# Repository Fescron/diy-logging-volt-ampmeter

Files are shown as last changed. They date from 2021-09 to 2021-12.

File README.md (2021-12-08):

# DIY Logging Volt/Ampmeter








<br/>

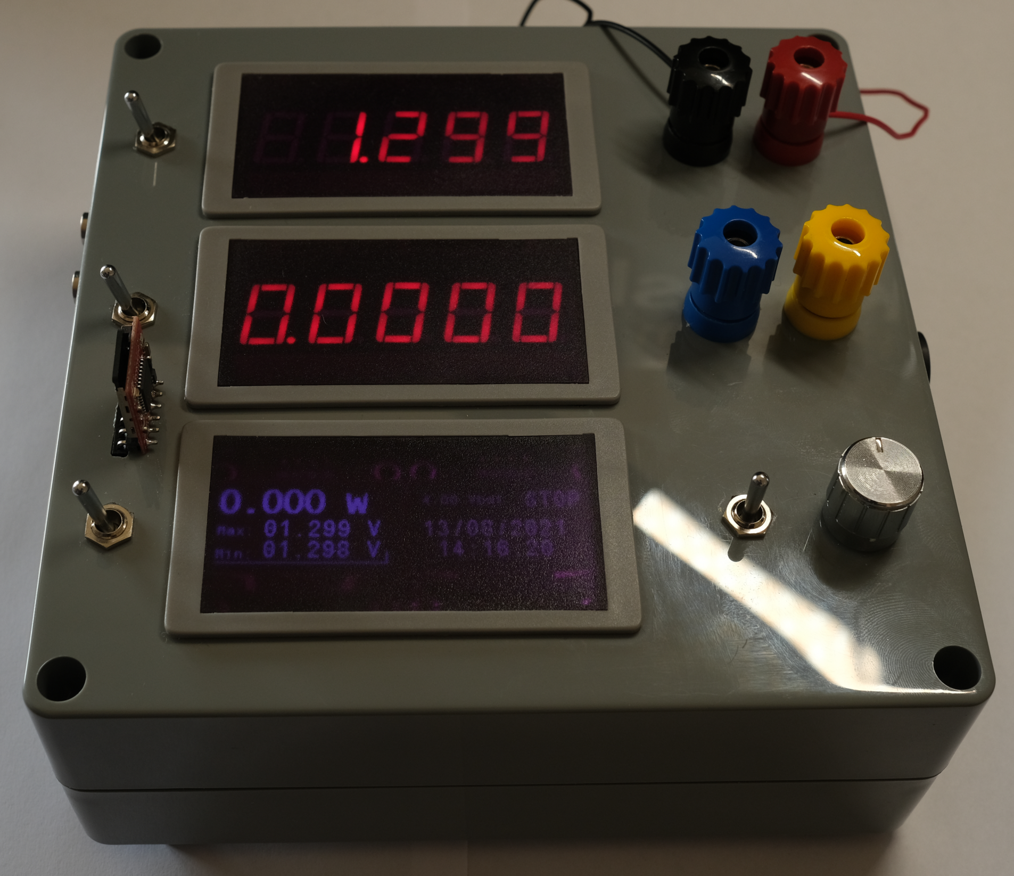
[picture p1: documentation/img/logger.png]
DIY Logging Volt/Ampmeter


<br/>

| Quick access links | |
|---|-----|
| [Carrier board v1.0 schematic (PDF)](hardware/high-accuracy-logging-volt-ampmeter/high-accuracy-logging-volt-ampmeter.pdf) | [Doxygen code documentation of individual files and methods](https://fescron.github.io/diy-logging-volt-ampmeter/files.html) |
| [Wiring diagram v1.0 (PDF)](hardware/wiring-diagram_diy-logging-volt-ampmeter/wiring-diagram_diy-logging-volt-ampmeter.pdf) | [Doxygen TODO's](https://fescron.github.io/diy-logging-volt-ampmeter/todo.html) |

<br/>

This battery-powered logging volt/ampmeter was made with the intention to easily get `.CSV` files filled with voltage/current/power measurements on a SD-card to plot and use this data further. It is supposed to have the same functionality as much more expensive dataloggers, with the added benefit of the ability to change the firmware to add more functions.

<br/>

## 0 - Table of Contents

- [DIY Logging Volt/Ampmeter](#diy-logging-voltampmeter)
  - [0 - Table of Contents](#0---table-of-contents)
  - [1 - Construction](#1---construction)
  - [2 - Usage](#2---usage)
  - [3 - Bash script to generate plots (logplot)](#3---bash-script-to-generate-plots-logplot)
  - [4 - Additional hardware changes (carrier board v1.0)](#4---additional-hardware-changes-carrier-board-v10)
  - [5 - Future code-additions](#5---future-code-additions)

<br/>

## 1 - Construction

DIY Logging Volt/Ampmeter

<br/>

The device consists of **two Chinese** (but very accurate and highly functional) **meters** ([BY56W 50V](https://aliexpress.com/item/32840631947.html) and [BY56W 5A](https://aliexpress.com/item/32839044728.html)) with independent power-supplies so no *common-mode* errors can occur. They can be individually powered on or off with **toggle switches** left of these meters. On the right of them are **combination banana- and screw-terminals** to easily connect measurement cables. The black and red one are the negative and positive terminal of the voltmeter, the blue and yellow one are the negative and positive terminal of the current meter. In series with the latter plugs and the current meter are a **5A 5x10mm fuse** (fitted in a holder on right right side of the logger), along with an **5V internal NC-relay** (with a [5V boostconverter](https://aliexpress.com/item/32891706812.html) and protection-diode) to open the current connection in certain scenarios (over-voltage, over-current, under-voltage, ...). Currently no code is written to use this relay functionality.

On the bottom a **third module** with the same shell as the voltage and current meters (I asked the Chinese store if they could sell me some) is situated with **two [1.3" 128x64 I2C OLED-displays](https://aliexpress.com/item/32830144222.html)** and a **STM32 Blue-Pill board** (with a genuine (!) ST `STM32F103C8T6` microcontroller). This functions as the brains of the whole unit. This bottom module can also be switched on or off with the **toggle switch** to the left. The display-module *asks* the two meters for measurement values and does additional conversions and calculations with them, drives the displays, keeps the time with its **internal RTC and 3V coincell backup-battery**, reads the battery voltage, outputs the measurements to the UART port on top, ... Next to the bottom module an **up/down monostable toggle switch** and **[pressable rotary encoder](https://aliexpress.com/item/32915420023.html)** can be used to start or stop logging, view measurements, change settings, ...

This module however **does not write the data to a SD-card directly**. For this a **[Sparkfun OpenLog](https://www.sparkfun.com/products/13712) module** has to be plugged in to the **external UART port on top**. Because of the way the firmware is developed, a new `.TXT` file is created each time a new measurement-session is started. The resulting file can be easily renamed to a `.CSV` file to facilitate importing in *Excel* or *OpenOffice Calc*. The first line of the file contains a header which explains what data goes where in the following measurement-lines. The last two lines of the file contain another header with corresponding data like date, total runtime, capacity and maximum/minimum values.

The whole thing is powered by **two (parallel) 18650 batteries** in a [battery holder](https://aliexpress.com/item/32832636191.html). A [charge and battery-protection PCB](https://aliexpress.com/item/32666559864.html) facilitates charging at 1A using **USB Type-C** on the left side of the meter. I used a [breakout-board](https://aliexpress.com/item/4001299632280.html) with two 5.1k resistors on the `CC1` and `CC2` pins to activate the 5V output on USB-PD compliant chargers. Above this Type-C port ***charging* and *done* LED's** are also fitted. Right of this the **programming-port** and two **external GPIO-pins** with a 3.3V and GND terminal on *Dupont*-connectors are situated. These two external GPIO-pins however currently have no function. Internally there also is a **buzzer** which can be used to signal various states, but no code is written to use this functionality as well. Some buck-boost converters (after the toggle switches) are also placed on a prototype-PCB to convert the battery voltage to 5V (with [these boostconverters](https://aliexpress.com/item/32891706812.html)) for the meters and 3.3V (with [this buck/boostconverter](https://aliexpress.com/item/32822323191.html)) for the bottom STM32-display-module.

The picture below depicts the internal wiring-diagram, standalone modules/boards are surrounded in blue frames.

<br/>

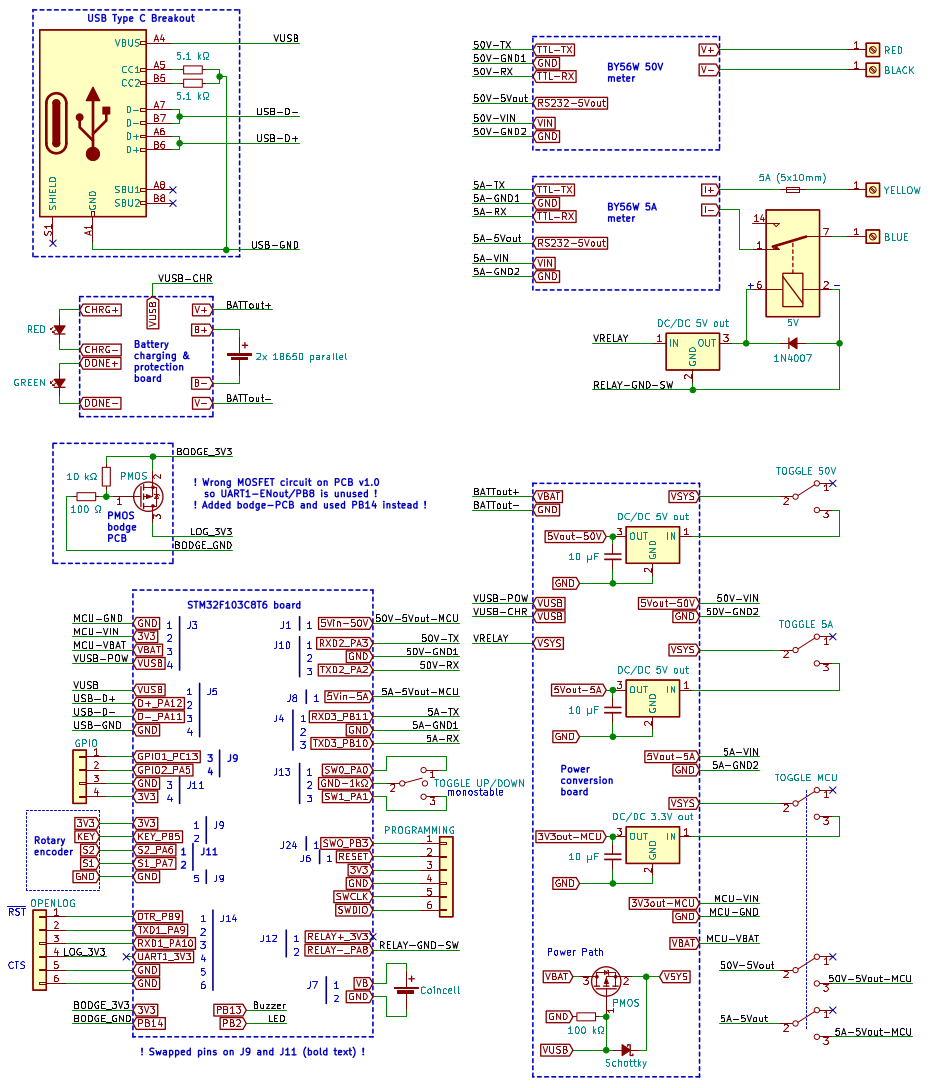
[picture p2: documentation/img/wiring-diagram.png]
Wiring diagram


<br/>

## 2 - Usage

The **up/down monostable toggle-switch** and **pressable rotary encoder** on the right of the bottom display-module are used to switch between display-pages and to set various settings.

The **left display** always indicates the power on the top. If the display is selected (*selection-line* drawn on the bottom of the display) the rotary encoder can be used to switch between the different pages to display additional information: max/min voltage, max/min current and calculated capacity in Ah and Wh. Upon an encoder-press the displayed information can be reset (if the logger is not saving data to a SD-card). Below these three available pages on the left display are depicted.

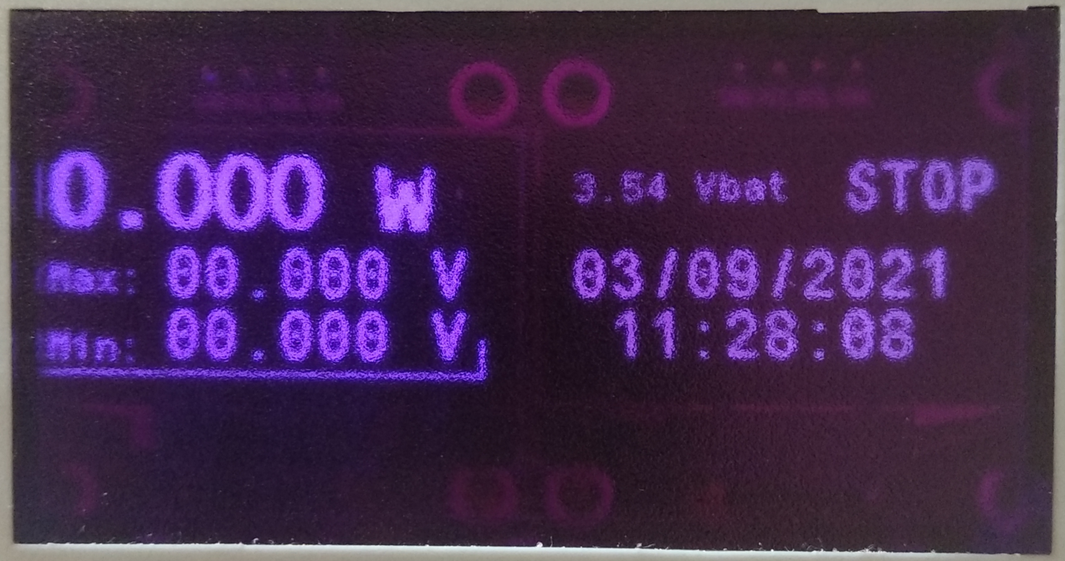
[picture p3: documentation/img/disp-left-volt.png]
Left display selected, max/min volt
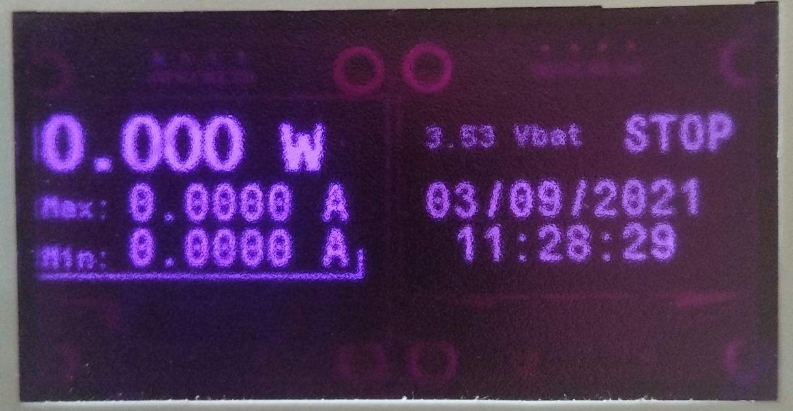
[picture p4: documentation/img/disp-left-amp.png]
Left display selected, max/min amp
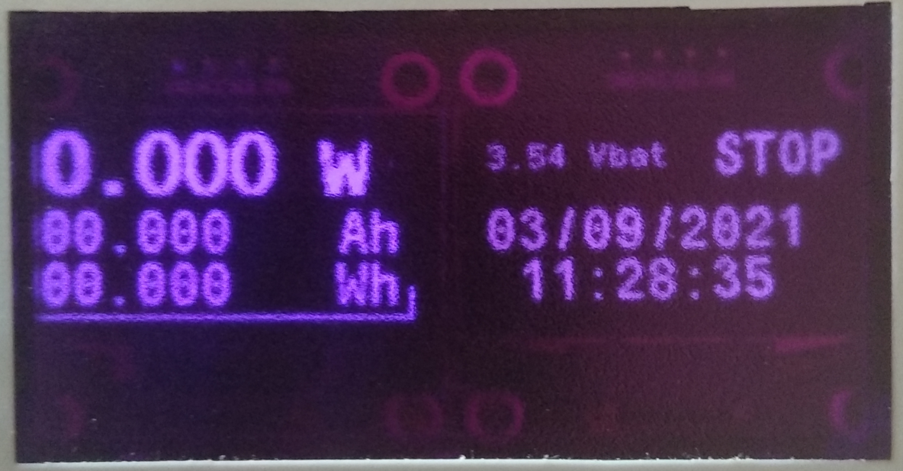
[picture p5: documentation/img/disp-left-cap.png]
Left display selected, capacity


<br/>

A down-press on the monostable toggle-switch changes the selected display. The *selection-line* on the bottom of the display will be moved to the newly selected display.

The **right display** always indicates the internal battery voltage and state of the logger (`STOP/START/RUN/SAVE`) on the top. If this display is selected (*selection-line* drawn on the bottom of the display) the rotary encoder can again be used to switch between the different pages to display additional information. The first page displays the current date and time, and pressing the encoder enables the user to change this information. Values are changed by rotating the encoder, the value (for example the day) is saved on an encoder-press, and the next item (for example the month) can now be edited. The second page displays the period between measurements saved to the logfile with the external logger. Pressing the encoder activates the ability to change the period by rotating the encoder, pressing it again saves the value. The third page displays the runtime if the logger is saving data to the external logger. Below these three available pages on the right display are depicted.

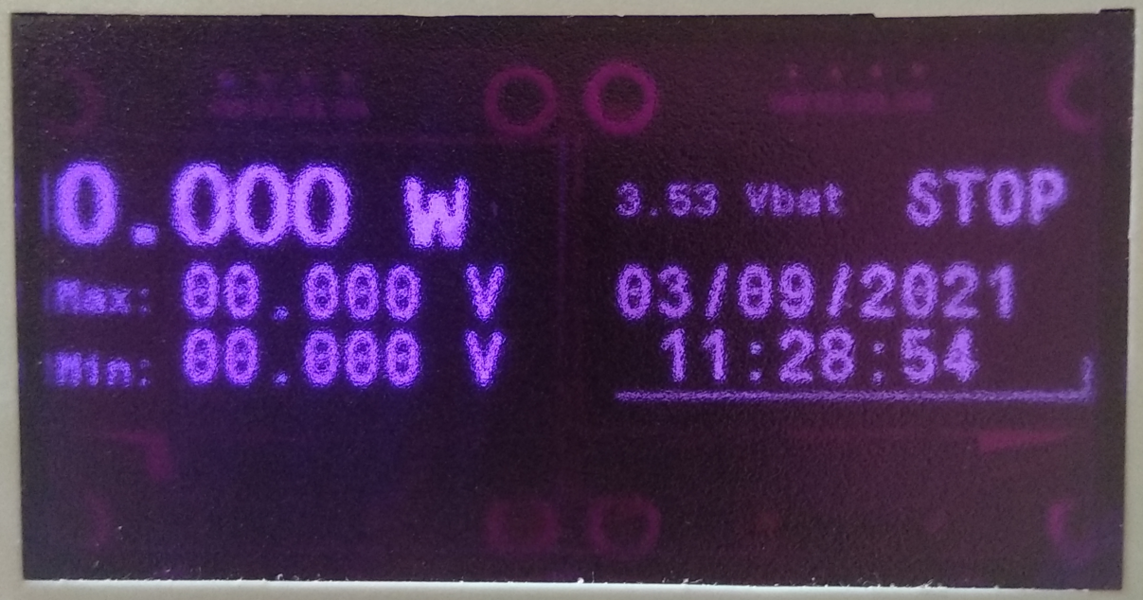
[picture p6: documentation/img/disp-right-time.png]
Right display selected, date/time
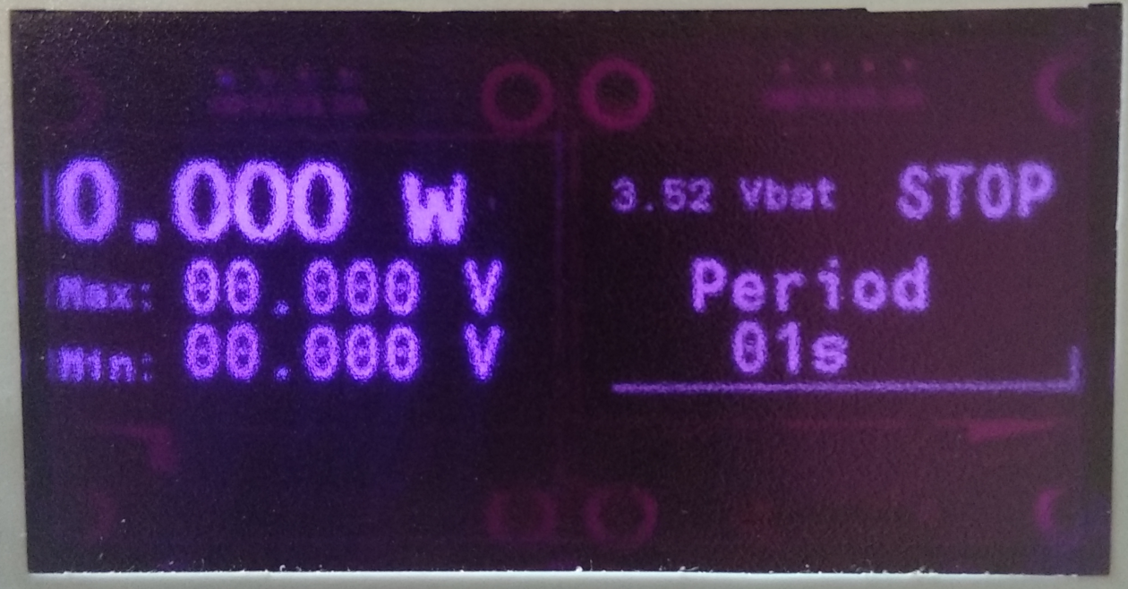
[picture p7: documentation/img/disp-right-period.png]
Right display selected, measurement period
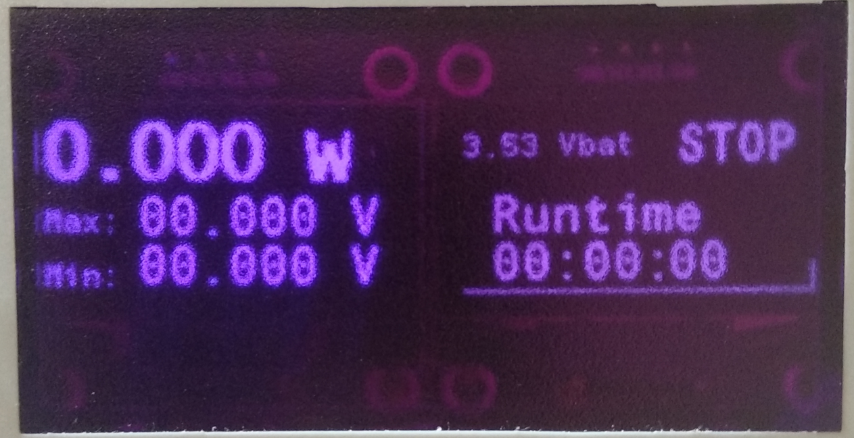
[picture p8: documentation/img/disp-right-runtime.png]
Right display selected, runtime


<br/>

An up-press on the monostable toggle switch (if the logger is in `STOP`-mode) powers-up the external logger (`START`) and writes the *header*, along with a first measurement-line to the `.TXT` file (`SAVE`). Then the logger waits (`RUN`) until the measurement-period runs out and writes another measurement to the file (`SAVE`). Another up-press on the monostable toggle switch stops the logging and writes two more lines to the end of the file including data as the date, total runtime, capacity, max/min values, ... An example of the resulting data in such a `.TXT` file is depicted below.

```
Time [hour:min:sec],Runtime [hour:min:sec],Voltage [V],Current [A],Power [W]
17:46:21,00:00:01,1.291,0.0000,0.000
17:46:23,00:00:03,1.291,0.0000,0.000
17:46:25,00:00:05,1.291,0.0000,0.000
17:46:27,00:00:07,1.291,0.0000,0.000
17:46:29,00:00:09,0.875,0.0000,0.000
17:46:31,00:00:11,1.092,0.0000,0.000
17:46:33,00:00:13,1.290,0.0000,0.000
Date [day/month/year],Runtime [hour:min:sec],Capacity [Ah],Capacity [Wh],Max Volt [V],Min Volt [V],Max Curr [A],Min Curr [A]
17/08/2021,00:00:13,00.000,00.000,01.291,00.000,0.0000,0.0000
```

<br/>

## 3 - Bash script to generate plots (logplot)

To easily convert the `.txt`/`.csv` files from this meter and get **plots in PDF-form**, a bash-script using `gnuplot` and `ps2pdf`/`imagemagick` was created. To create a PDF-plot of a file (`LOG00110.TXT`) with the title "Title" and subtitle "Subtitle", and to make sure the capacity and max/min voltage and current values are displayed above the graph, one can use the following command:

```bash
logplot -f "LOG00110.TXT" -t "Title" -st "Subtitle" -av
```

<br/>

Below is a list of all of the possible commands, which can also be shown with the command `logplot -h`. The bash-script itself can be found [here](software/logplot)

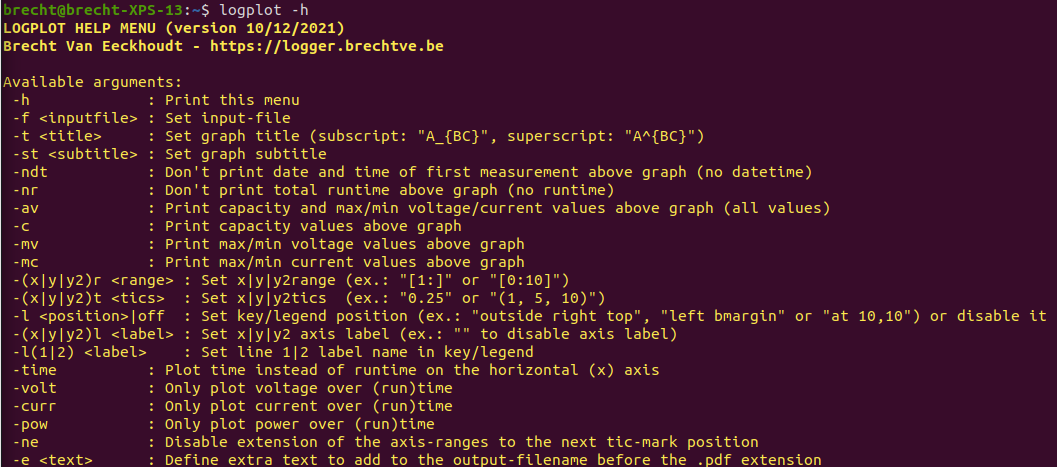
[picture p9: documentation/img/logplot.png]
Logplot help menu


<br/>

## 4 - Additional hardware changes (carrier board v1.0)

To simplify the firmware for the rotary encoder logic some pins were swapped around on header `J9` and `J11`. This is highlighted by bold text on the wiring-diagram on the **STM32F103C8T6 board**.

Unfortunately a wrong MOSFET was used for the function to power the external Openlog UART datalogger on or off. This means that MCU pin `UART1-ENout/PB8` is unused and a **PMOS bodge PCB** was constructed. This can be seen on the wiring-diagram. MCU pin `PB14` is used instead to power the logger.

<br/>

## 5 - Future code-additions

The firmware is constructed with a lot of extra variables to facilitate the functionality to only update changed values on the displays. This speeds up the code but does however create a lot of *overhead*. In the future this can certainly be optimized.

As of yet not all of the hardware is used, like for example the relay and buzzer. All TODO's can be found in the [Doxygen TODO's](https://fescron.github.io/diy-logging-volt-ampmeter/todo.html).

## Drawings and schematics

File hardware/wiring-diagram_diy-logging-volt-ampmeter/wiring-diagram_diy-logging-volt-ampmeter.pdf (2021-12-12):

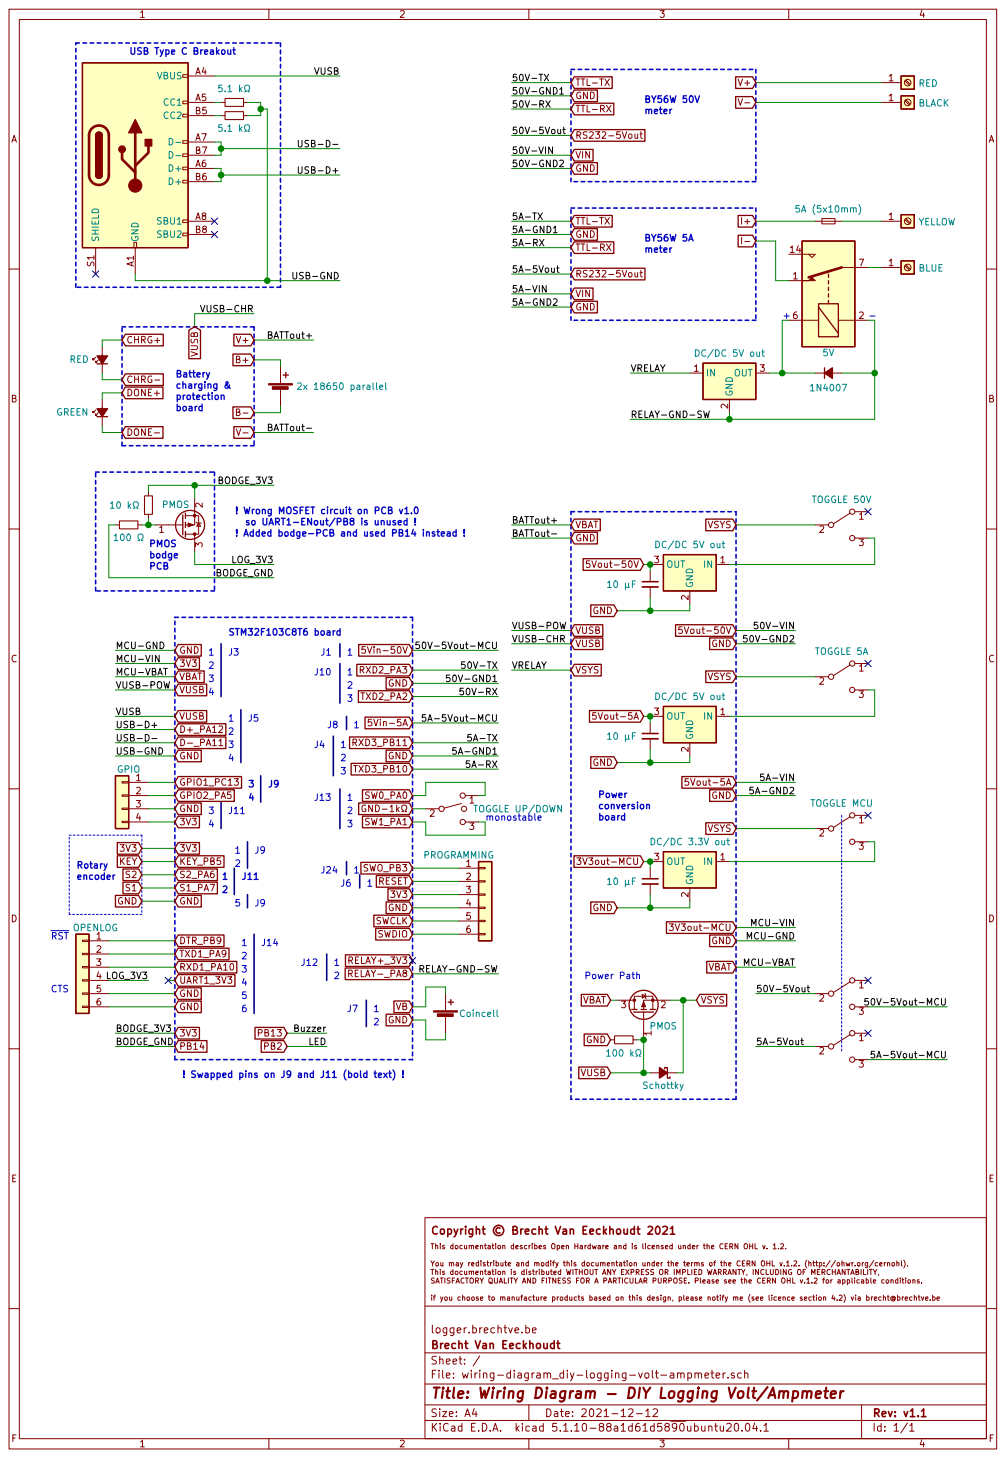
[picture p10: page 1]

2 OUT 3 DC/DC 5V out 1

! Wrong MOSFET circuit on PCB v1.0
so UART1-ENout/PB8 is unused !
! Added bodge-PCB and used PB14 instead ! 3

! Swapped pins on J9 and J11 (bold text) !

Copyright © Brecht Van Eeckhoudt 2021

This documentation describes Open Hardware and is licensed under the CERN OHL v. 1.2.

You may redistribute and modify this documentation under the terms of the CERN OHL v.1.2. (http://ohwr.org/cernohl).

logger.brechtve.be
File: wiring-diagram_diy-logging-volt-ampmeter.sch Sheet: / Brecht Van Eeckhoudt

Id: 1/1 Title: Wiring Diagram - DIY Logging Volt/Ampmeter

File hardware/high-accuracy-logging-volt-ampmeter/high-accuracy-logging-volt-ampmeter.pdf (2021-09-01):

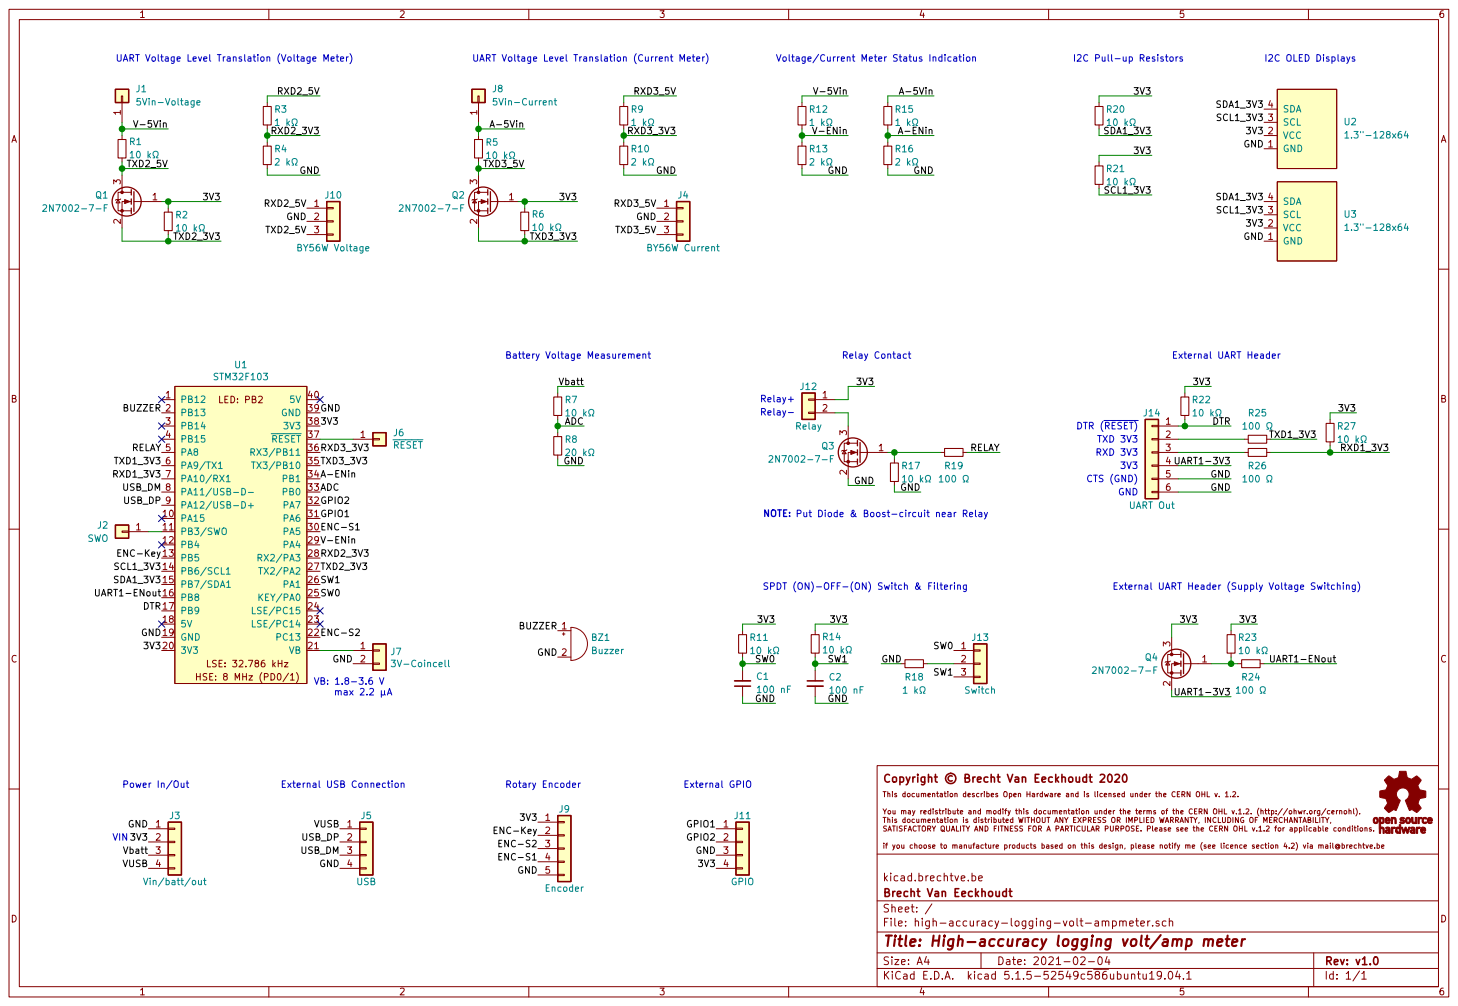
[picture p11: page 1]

RXD 3V3 SPDT (ON)-OFF-(ON) Switch & Filtering

NOTE: Put Diode & Boost-circuit near Relay VB: 1.8-3.6 V

External UART Header (Supply Voltage Switching)

File: high-accuracy-logging-volt-ampmeter.sch Sheet: / Brecht Van Eeckhoudt kicad.brechtve.be Copyright © Brecht Van Eeckhoudt 2020

This documentation describes Open Hardware and is licensed under the CERN OHL v. 1.2.

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

Id: 1/1 Title: High-accuracy logging volt/amp meter

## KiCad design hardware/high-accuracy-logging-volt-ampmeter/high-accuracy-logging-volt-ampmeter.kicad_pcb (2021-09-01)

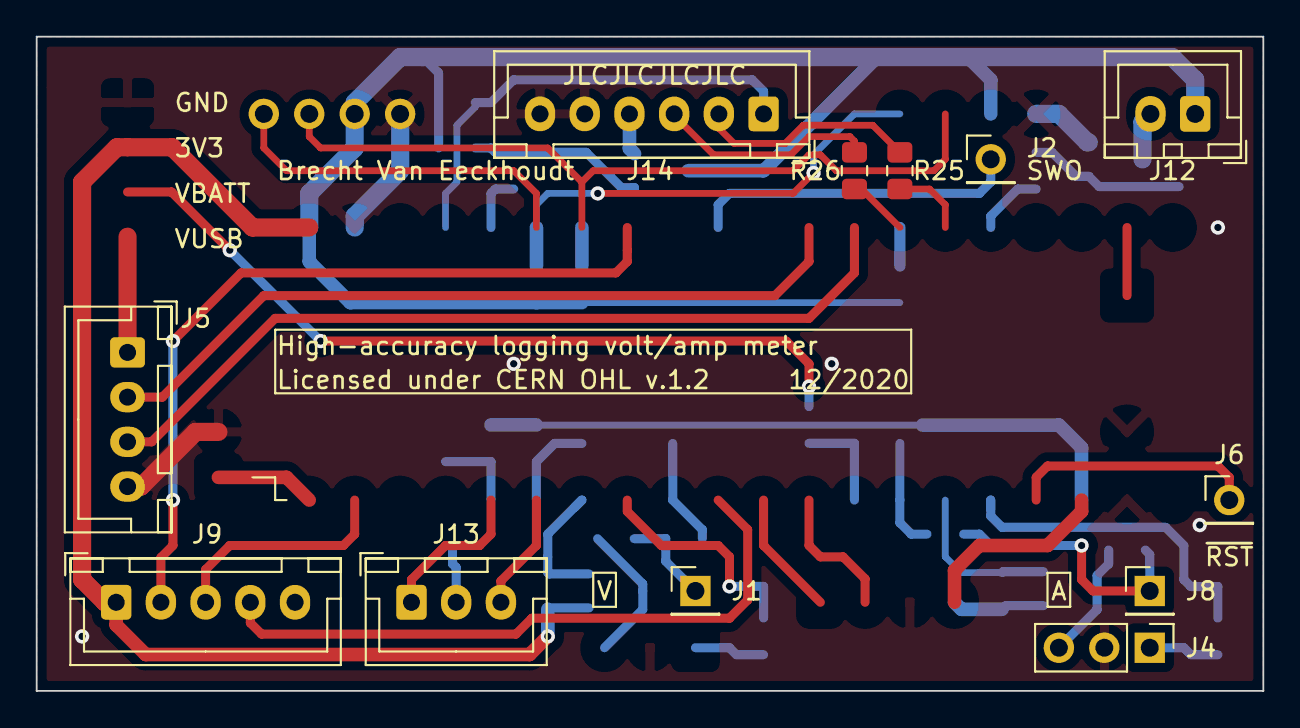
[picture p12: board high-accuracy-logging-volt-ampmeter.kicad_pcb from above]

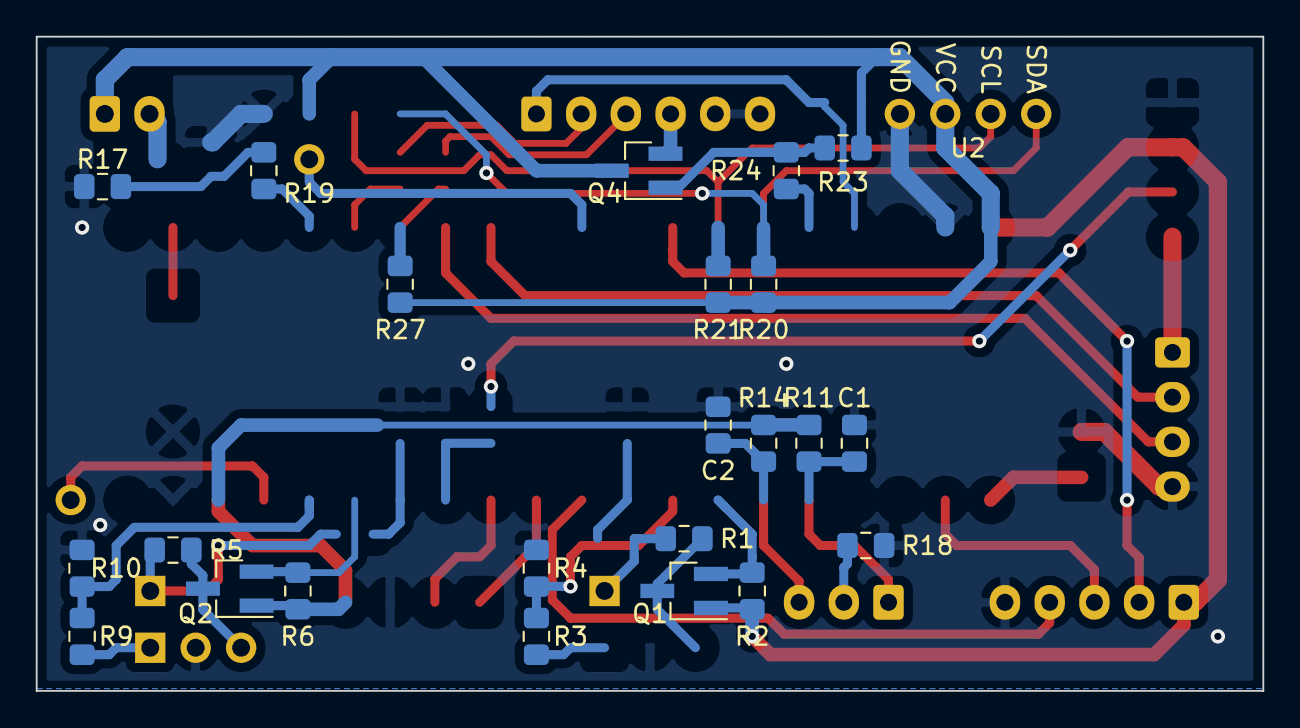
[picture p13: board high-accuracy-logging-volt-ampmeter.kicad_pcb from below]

Board: 2 copper layers, 68.6 x 36.6 mm, 37 parts (24 on the bottom side), 22 nets.

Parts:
C1, C2: 100 nF; C_0805_2012Metric_Pad1.15x1.40mm_HandSolder
G1: Symbol_OSHW-Logo_11.4x12mm; OSHW-Logo_5.7x6mm_SolderMask
J1: 5Vin-Voltage; PinHeader_1x01_P2.54mm_Vertical
J2: SWO; PinHeader_1x01_P2.54mm_Vertical
J4: BY56W Voltage; PinHeader_1x03_P2.54mm_Vertical
J5: USB; JST_XH_B4B-XH-A_1x04_P2.50mm_Vertical
J6: ~RESET; PinHeader_1x01_P2.54mm_Vertical
J8: 5Vin-Current; PinHeader_1x01_P2.54mm_Vertical
J9: Encoder; JST_XH_B5B-XH-A_1x05_P2.50mm_Vertical
J12: Relay; JST_XH_B2B-XH-A_1x02_P2.50mm_Vertical
J13: Switch; JST_XH_B3B-XH-A_1x03_P2.50mm_Vertical
J14: UART Out; JST_XH_B6B-XH-A_1x06_P2.50mm_Vertical
Q1, Q2, Q4: 2N7002-7-F; SOT-23_Handsoldering
R1, R2, R5, R6, R11, R14, R17, R20, R21, R23, R27: 10 kΩ; R_0805_2012Metric_Pad1.15x1.40mm_HandSolder
R3, R9, R18: 1 kΩ; R_0805_2012Metric_Pad1.15x1.40mm_HandSolder
R4, R10: 2 kΩ; R_0805_2012Metric_Pad1.15x1.40mm_HandSolder
R19, R24, R25, R26: 100 Ω; R_0805_2012Metric_Pad1.15x1.40mm_HandSolder
U2: 1.3; 1.3INCH-128x64-I2C-OLED-NoHoles

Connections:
/3V3: J9.1, J12.1, Q1.1, Q2.1, Q4.3, R2.1, R6.2, R11.1, R14.2, R20.1, R21.1, R23.1, R27.1, U2.2
/A-5Vin: J8.1, R5.1
/GND: C1.1, C2.2, J4.2, J5.4, J9.5, J14.5, J14.6, R4.2, R10.2, R17.2, R18.2, U2.1
/RXD1_3V3: R26.2, R27.2
/RXD2_3V3: R3.2, R4.1
/RXD3_3V3: R9.2, R10.1
/RXD3_5V: J4.1, R9.1
/SCL1_3V3: R21.2, U2.3
/SDA1_3V3: R20.2, U2.4
/SW0: C1.2, J13.1, R11.2
/SW1: C2.1, J13.3, R14.1
/TXD2_3V3: Q1.2, R2.2
/TXD2_5V: Q1.3, R1.1
/TXD3_3V3: Q2.2, R6.1
/TXD3_5V: J4.3, Q2.3, R5.2
/UART1-3V3: J14.4, Q4.2
/V-5Vin: J1.1, R1.2
unnamed: J13.2, R18.1
unnamed: J14.2, R25.2
unnamed: J14.3, R26.1
unnamed: R17.1, R19.2
unnamed: Q4.1, R23.2, R24.2

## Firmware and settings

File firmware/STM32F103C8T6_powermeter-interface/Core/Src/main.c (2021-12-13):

/* USER CODE BEGIN Header */

/***************************************************************************//**
 * @file main.c
 * @brief Main source-file for the high-precision logging voltage/current meter project.
 * @details
 *   The code in this project asks two BY56W volt/current meters for measurements,
 *   calculates a few additional values (min/max/power/Ah/Wh) with these, prints
 *   them to displays and sends them (with time/date values) to a UART port so
 *   a Sparkfun OpenLog can log these measurements to a `.TXT` file, which can
 *   eventually be renamed to a `.CSV` so the measurements can be easily plotted.
 * @version 1.2
 * @author Brecht Van Eeckhoudt
 *
 * ******************************************************************************
 *
 * @section Versions
 *
 *   @li v1.0: Initial version.
 *   @li v1.1: Started printing date before time for each measurement-line, removed day-writing in footer.
 *   @li v1.2: Compared power floats more reliably.
 *
 * ******************************************************************************
 *
 * @todo
 *   **Things to do in the near future:**@n
 *     - Check Ah/Wh calculations.
 *     - Check if the power/Ah/Wh calculations are done using wrong/old measurements.
 *     - Handle uint32_t wraparound for time between calculations measurements and waiting time.
 *     - Don't send/do certain functions if one of the meters is powered down.
 *
 * @todo
 *   **Long-term future improvements:**@n
 *     - Add function to stop measurements when the voltage/current is (above/) below a certain value.
 *     - Add external temperature reading functionality.
 *     - Add internal temperature reading functionality (`MX_ADC1_Init();`).
 *     - Add interrupt-logging functionality.
 *     - Add relay-opening functionality.
 *     - Add "manual measurement-mode" to log on up-button press.
 *     - Add "performance-mode" with no display refreshes.
 *        - (sub-page on right display, start/stop with up, beeps for confirmation)
 *     - Add low-battery beeping.
 *     - Add buzzer functionality using TIM2 (`MX_TIM2_Init();`).
 *        -  (short beep button-press, longer when measurement taken, add ON/OFF settings page)
 *     - Optimize encoder logic so there is less copy-pasting.
 *     - Add debounce logic to `getSW0();`, `getSW1();` and `getENCkey();`.
 *     - Use `LL_GetTick();` instead of `HAL_GetTick();`?
 *     - Add circular pages for setting day/month/hour/minute/second (`changeDateTime`).
 *     - Add day-checking in function of the month?
 *     - Use defines for circular pages?
 *     - Start using `aBY56W_ContinuousRead`? Send on every meter power-up?
 *     - Only one while-loop (`USART_HandleContinuousReception`) when one meter is
 *       connected, way more if both are? Optimize this?
 *     - Add overflow catch if data.voltage/current are negative values?
 *        - `data.power > 999.999`, `data.ah > 9999.999`, `data.wh > 9999.999`
 *     - Remove all Segger-RTT functionality?
 *     - Store settings in power-down-safe memory.
 *
 * ******************************************************************************
 *
 * @section License
 *
 *   **Copyright (C) 2021 - Brecht Van Eeckhoudt**
 *
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
 *   *A copy of the GNU General Public License can be found in the `LICENSE`
 *   file along with this source code.*
 *
 *   @n
 *
 *   Some methods also use code obtained from examples from STMicroelectronics.
 *
 *   **Copyright (c) 2020 STMicroelectronics. All rights reserved.**
 *
 *   These sections are licensed by ST under BSD 3-Clause license, the "License";
 *   One may not use these example files except in compliance with the License.
 *   One may obtain a copy of the License at: opensource.org/licenses/BSD-3-Clause
 *
 ******************************************************************************/

/* USER CODE END Header */
/* Includes ------------------------------------------------------------------*/
#include "main.h"
#include "adc.h"
#include "i2c.h"
#include "tim.h"
#include "gpio.h"

/* USER CODE BEGIN Includes */

#include "usart.h"      /* UART communication functionality */
#include "SEGGER_RTT.h" /* Segger RTT debugging functionality */
#include "util.h"       /* Utility functionality */
#include "conversion.h" /* Conversion and settings */
#include "display.h"    /* Display functionality */
#include "rtc.h"        /* Real Time Clock and Calendar functionality */

/* USER CODE END Includes */

/* USER CODE BEGIN PD */

/** Max amount of while loop passes before exiting the while loop early (~meter unresponsive) */
#define MAX_WHILELOOPS_METER_RESPONSE 9000

/** Waiting time before shutting down the external UART logger after writing the footer */
#define SHUTDOWN_DELAY_UART_MODULE_MS 500

/** Waiting time for an external UART power-up message before writing the header */
#define STARTUP_DELAY_UART_MODULE_MS  2000

/** Time between battery voltage measurements */
#define VBAT_MEASUREMENT_PERIOD_S     10

/* USER CODE END PD */


/* USER CODE BEGIN PV */

/* BY56W meter commands */
static const uint8_t aBY56W_SingleRead[4]     = {0x88, 0xAE, 0x00, 0x11}; /* 0x00 = Device address */
//static const uint8_t aBY56W_ContinuousRead[4] = {0x88, 0xAE, 0x00, 0x21}; /* 0x00 = Device address */
//static const uint8_t aBY56W_StopRead[4]       = {0x88, 0xAE, 0x00, 0x01}; /* 0x00 = Any byte */

/* Data in structs */
struct Data_t         data;     /* Measurement data (changes a lot) */
struct cData_t        cData;    /* Measuremtn data converted to char-arrays */
struct Settings_t     settings; /* General data/settings (changes less frequently */
struct RTC_dateTime_t rtc;      /* Date and time */

/** LUT for period selection [s] (0 = as fast as possible) */
static const uint16_t LUT_period_s[16] = {0, 1, 2, 5, 10, 15, 30, 60, 120, 300, 600, 900, 1800, 3600, 7200, 18000};

/** Length of LUT */
static const uint8_t LUT_period_s_length = 16;

/* USER CODE END PV */

void SystemClock_Config(void);
/* USER CODE BEGIN PFP */

void writeHeader(void);
void writeFooter(void);
void writeMeasurements(void);
void checkEncoder(void);
void checkSwitches(void);

/* USER CODE END PFP */

/**
  * @brief  The application entry point.
  * @retval int
  */
int main(void)
{
  /* MCU Configuration--------------------------------------------------------*/

  /* Reset of all peripherals, Initializes the Flash interface and the Systick. */
  HAL_Init();

  /* Configure the system clock */
  SystemClock_Config();

  /* Initialize all configured peripherals */
  MX_GPIO_Init();
//  MX_ADC1_Init();
  MX_I2C1_Init();
  MX_ADC2_Init();
  MX_TIM3_Init();
//  MX_TIM2_Init();
  /* USER CODE BEGIN 2 */

  /* Power down UART voltage output */
  LL_GPIO_SetOutputPin(UART1_3V3out_GPIO_Port, UART1_3V3out_Pin); /* P-MOS so inverted logic! */

  /* Power up UART DTR (~reset)-pin so we're not resetting the module */
  LL_GPIO_SetOutputPin(UART1_DTRout_GPIO_Port, UART1_DTRout_Pin);


  /* Enable output channel 1 (rotary encoder) */
  LL_TIM_CC_EnableChannel(TIM3, LL_TIM_CHANNEL_CH1 | LL_TIM_CHANNEL_CH2);

  /* Enable counter */
  LL_TIM_EnableCounter(TIM3);

  /* Force update generation */
  LL_TIM_GenerateEvent_UPDATE(TIM3);


  /* Initialize date/time functionality */
  RTC_Init();


  /* Enable the update interrupt (logging-timing) */
//  LL_TIM_EnableIT_UPDATE(TIM2); // TODO change to buzzer timing

  /* Enable counter */
//  LL_TIM_EnableCounter(TIM2); // TODO change to buzzer timing

  /* Force update generation */
//  LL_TIM_GenerateEvent_UPDATE(TIM2); // TODO change to buzzer timing


  /* Initialize UART functionality */
  USART1_INIT();
  USART2_INIT();
  USART3_INIT();

  /* Initialize structs */
  initDataStruct();
  initSettingsStruct();

  /* Activate ADC for battery voltage measurements */
  Activate_ADC();

  /* Clear Terminal for Segger RTT functionality */
  SEGGER_RTT_WriteString(0, RTT_CTRL_CLEAR"START\r\n");

  /* Initialize displays */
  initDisplays();

  /* Disable buzzer */
//  LL_GPIO_ResetOutputPin(Buzzer_GPIO_Port, Buzzer_Pin);

//	  LL_GPIO_TogglePin(Relay_GPIO_Port, Relay_Pin);
//	  LL_GPIO_TogglePin(Buzzer_GPIO_Port, Buzzer_Pin);


//  SEGGER_RTT_printf(0, "%sTime:%s%s %.7d\n\r",
//                        RTT_CTRL_RESET,
//                        RTT_CTRL_BG_BRIGHT_RED,
//                        RTT_CTRL_TEXT_BRIGHT_WHITE,
//                        1111111
//                        );
//  SEGGER_RTT_WriteString(0, RTT_CTRL_RESET"Red: "RTT_CTRL_TEXT_BRIGHT_RED"This text is red."RTT_CTRL_TEXT_BLACK""RTT_CTRL_BG_BRIGHT_RED"This background is red. "RTT_CTRL_RESET"Normal text again.\n\r");
//	SEGGER_RTT_printf(0, "Value = %x\r\n", value);
//	SEGGER_RTT_printf(0, RTT_CTRL_RESET"%-.3d ", value);
//	SEGGER_RTT_printf(0, RTT_CTRL_TEXT_BRIGHT_RED"0x%.2x ", value);


  /* USER CODE END 2 */

  /* Infinite loop */
  /* USER CODE BEGIN WHILE */
  while (1)
  {
    /* USER CODE END WHILE */

    /* USER CODE BEGIN 3 */

	  checkEncoder();
	  checkSwitches();

	  USART2_SendCommand(aBY56W_SingleRead, 4); /* Voltage */
	  USART3_SendCommand(aBY56W_SingleRead, 4); /* Current */

	  uint16_t whileLoops = 0;

	  while (!(data.voltReceived) && !(data.currReceived) && (whileLoops < MAX_WHILELOOPS_METER_RESPONSE))
	  {
		  USART_HandleContinuousReception();
		  whileLoops++;
	  }

//	  SEGGER_RTT_printf(0, "%d ", whileLoops);

	  if (whileLoops < MAX_WHILELOOPS_METER_RESPONSE)
	  {
		  /* Store tick-value of latest measurements */
		  if (data.latestMScounter == 0)
		  {
			  data.msCounter1 = HAL_GetTick();
			  data.latestMScounter = 1;
		  }
		  else if (data.latestMScounter == 1)
		  {
			  data.msCounter0 = HAL_GetTick();
			  data.latestMScounter = 0;
		  }
	  }

	  /* Calculate power, Ah and Wh */
	  if (data.voltReceived || data.currReceived)
	  {
		  data.power = data.voltage * data.current;
		  if (data.power > 999.999) data.power = 999.999;

		  /* Convert floats to uint32_t (power has 3 decimal places: *1000) */
		  uint32_t oldPower = FLOAT_TO_INT(data.oldPower*1000);
		  uint32_t power = FLOAT_TO_INT(data.power*1000);

		  if (oldPower != power)
		  {
			  data.oldPower = data.power;
			  data.newPow = 1;
		  }

		  /* Calculate time between measurements */
		  uint32_t msTime = 0;
		  if (data.latestMScounter == 0) msTime = data.msCounter0 - data.msCounter1;
		  else if (data.latestMScounter == 1) msTime = data.msCounter1 - data.msCounter0;

//			  SEGGER_RTT_printf(0, "%dms ", msTime);

		  data.ah += data.current * ((float)msTime / 3600000.0);
		  if (data.ah > 9999.999) data.ah = 9999.999;

		  data.newAh = 1;

		  data.wh += data.power * ((float)msTime / 3600000.0);
		  if (data.wh > 9999.999) data.wh = 9999.999;

		  data.newWh = 1;
	  }

	  data.voltReceived = 0;
	  data.currReceived = 0;

	  /* Change variables if one second is elapsed */
	  if (decSecondPassed())
	  {
		  /* Signal (second) conversion logic */
		  settings.newSec = 1;

		  /* Get new RTC values if not changing the date/time manually */
		  if ((settings.changeDateTime == 0) && (settings.secPassed == 0)) readFromRTC();

		  /* Update runtime if running */
		  if ((settings.mode == 1) && settings.loggerReady)
		  {
			  if (settings.remMeasPeriodS > 0) settings.remMeasPeriodS--;

			  /* Re-calculate runtime */
			  if (data.runSecs < 59) data.runSecs++;
			  else if (data.runSecs == 59)
			  {
				  if (data.runMins < 59) data.runMins++;
				  else if (data.runMins == 59)
				  {
					  if (data.runHours < 99) data.runHours++;

					  data.newRunHours = 1; /* Display needs updating */
					  data.runMins = 0;
				  }
				  data.newRunMins = 1; /* Display needs updating */
				  data.runSecs = 0;
			  }
			  data.newRunSecs = 1; /* Display needs updating */
		  }

		  if (settings.vbatCounter > 0) settings.vbatCounter--;
		  else if (settings.vbatCounter == 0)
		  {
			  startBattVoltMeasurement();
			  settings.vbatCounter = VBAT_MEASUREMENT_PERIOD_S;
		  }
	  }

	  convertValues();

	  /* Stopped, Logger needs to be disabled */
	  if ((settings.mode == 0) && settings.headerSaved)
	  {
		  if (settings.msWaiting == 0)
		  {
			  /* Make sure all values are converted to chars */
			  forceConversion();

			  displaySaveIcon();
			  writeFooter();

			  /* Set waiting time */
			  settings.msWaiting = SHUTDOWN_DELAY_UART_MODULE_MS;
			  settings.msWaitingStart = HAL_GetTick();
		  }
		  else if ((HAL_GetTick() - settings.msWaitingStart) >= settings.msWaiting)
		  {
			  /* Disable power to logger */
			  LL_GPIO_SetOutputPin(UART1_3V3out_GPIO_Port, UART1_3V3out_Pin); /* P-MOS so inverted logic! */

			  /* Reset waiting functionality */
			  settings.msWaiting = 0;
			  settings.msWaitingStart = 0;

			  settings.loggerReady = 0;
			  settings.headerSaved = 0;
		  }
	  }

	  /* Just started, header not yet saved */
	  if ((settings.mode == 1) && !(settings.headerSaved))
	  {
		  if (settings.msWaiting == 0)
		  {
			  settings.remMeasPeriodS = 0; /* Force immediate measurement */
			  settings.rightPage = 2; /* Go to runtime sub-page */

			  /* Enable power to logger */
			  LL_GPIO_ResetOutputPin(UART1_3V3out_GPIO_Port, UART1_3V3out_Pin); /* P-MOS so inverted logic! */

			  /* Set waiting-time */
			  settings.msWaiting = STARTUP_DELAY_UART_MODULE_MS;
			  settings.msWaitingStart = HAL_GetTick();
		  }
		  else if (((HAL_GetTick() - settings.msWaitingStart) >= settings.msWaiting) || settings.loggerReady)
		  {
			  /* Reset values */
			  initDataStruct();
			  convertValues();

			  displaySaveIcon();
			  writeHeader();

			  /* Reset waiting functionality */
			  settings.msWaiting = 0;
			  settings.msWaitingStart = 0;

			  settings.loggerReady = 1; /* If we got here by timeout make sure the runtime logic will still work */
			  settings.headerSaved = 1;
		  }
	  }
	  /* Running, header already saved, amount of seconds necessary reached */
	  else if ((settings.mode == 1) && settings.headerSaved && (settings.remMeasPeriodS == 0))
	  {
		  settings.remMeasPeriodS = LUT_period_s[settings.measPeriodIndex];

		  displaySaveIcon();
		  writeMeasurements();

	  }

	  updateLeftDisplay();
	  updateRightDisplay();
	  finishDisplayUpdates();

	  /* Insert millisecond delay */
//	  SEGGER_RTT_printf(0, "Loop ");
//	  LL_mDelay(250);

  }
  /* USER CODE END 3 */
}

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
/* USER CODE BEGIN 4 */


/**************************************************************************//**
 * @brief
 *   Function to handle switch presses.
 *****************************************************************************/
void checkSwitches(void)
{
	/* UP */
	if (getSW0())
	{
		if ((settings.mode == 0) && !(settings.headerSaved) && (settings.changeDateTime == 0))
		{
			settings.mode = 1;
			settings.newMode = 1; /* Display needs updating */
		}
		else if (settings.mode == 1)
		{
			settings.mode = 0;
			settings.newMode = 1; /* Display needs updating */
		}

		setSW0(0); /* Interrupt handled */
	}

	/* DOWN */
	if (getSW1())
	{
		if (settings.selectedDisplay == 0) settings.selectedDisplay = 1;
		else if (settings.selectedDisplay == 1) settings.selectedDisplay = 0;

		settings.newSelDisplay = 1; /* Display needs updating */

		setSW1(0); /* Interrupt handled */
	}

	/* Encoder press */
	if (getENCkey())
	{
		/* Only change when not running */
		if (settings.mode == 0)
		{
			/* Reset value on selected LEFT page */
			if ((settings.selectedDisplay == 0) && (settings.leftPage == 0))
			{
				data.firstVolt  = 1;
				data.minVoltage = 0.0;
				data.newMinVolt = 1;
				data.maxVoltage = 0.0;
				data.newMaxVolt = 1;
			}
			else if ((settings.selectedDisplay == 0) && (settings.leftPage == 1))
			{
				data.firstCurr  = 1;
				data.minCurrent = 0.0;
				data.newMinCurr = 1;
				data.maxCurrent = 0.0;
				data.newMaxCurr = 1;
			}
			else if ((settings.selectedDisplay == 0) && (settings.leftPage == 2))
			{
				data.ah    = 0.0;
				data.newAh = 1;
				data.wh    = 0.0;
				data.newWh = 1;
			}

			/* Set values on selected RIGHT page */
			if ((settings.selectedDisplay == 1) && (settings.rightPage == 0))
			{
				if (settings.changeDateTime == 0)
				{
					settings.changeDateTime = 1; /* Start by changing day */
					settings.dateTimeChanged = 1; /* Force display update (a.o. underline) */
				}
				else if (settings.changeDateTime == 6) /* End by changing seconds */
				{
					settings.changeDateTime = 0;
					settings.dateTimeChanged = 1; /* Force display update (a.o. underline) */
					writeToRTC();
				}
				else if (settings.changeDateTime > 0)
				{
					settings.changeDateTime++;
					settings.dateTimeChanged = 1;
				}
			}
			else if ((settings.selectedDisplay == 1) && (settings.rightPage == 1))
			{
				/* Enable/disable period change on encoder turn */
				if (settings.changePeriod == 0)
				{
					settings.changePeriod = 1;
					settings.periodChanged = 1;
				}
				else if (settings.changePeriod == 1)
				{
					settings.changePeriod = 0;
					settings.periodChanged = 1;
				}
			}
			/* Directly change period on encoder press on runtime page */
			else if ((settings.selectedDisplay == 1) && (settings.rightPage == 2))
			{
				settings.rightPage = 1;
				settings.changePeriod = 1;
				settings.periodChanged = 1;
			}
		}

		setENCkey(0); /* Interrupt handled */
	}
}
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

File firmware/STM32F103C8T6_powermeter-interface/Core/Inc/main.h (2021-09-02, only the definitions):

#define SW0_Pin LL_GPIO_PIN_0
#define SW0_GPIO_Port GPIOA
#define SW0_EXTI_IRQn EXTI0_IRQn
#define SW1_Pin LL_GPIO_PIN_1
#define SW1_GPIO_Port GPIOA
#define SW1_EXTI_IRQn EXTI1_IRQn
#define V_ENin_Pin LL_GPIO_PIN_4
#define V_ENin_GPIO_Port GPIOA
#define A_ENin_Pin LL_GPIO_PIN_1
#define A_ENin_GPIO_Port GPIOB
#define LED_Pin LL_GPIO_PIN_2
#define LED_GPIO_Port GPIOB
#define Buzzer_Pin LL_GPIO_PIN_13
#define Buzzer_GPIO_Port GPIOB
#define UART1_3V3out_Pin LL_GPIO_PIN_14
#define UART1_3V3out_GPIO_Port GPIOB
#define Relay_Pin LL_GPIO_PIN_8
#define Relay_GPIO_Port GPIOA
#define ENC_Key_Pin LL_GPIO_PIN_5
#define ENC_Key_GPIO_Port GPIOB
#define ENC_Key_EXTI_IRQn EXTI9_5_IRQn
#define UART1_ENout_Pin LL_GPIO_PIN_8
#define UART1_ENout_GPIO_Port GPIOB
#define UART1_DTRout_Pin LL_GPIO_PIN_9
#define UART1_DTRout_GPIO_Port GPIOB
#define GPIO1_Pin LL_GPIO_PIN_5
#define GPIO1_Port GPIOA
#define GPIO2_Pin LL_GPIO_PIN_13
#define GPIO2_Port GPIOC

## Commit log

2021-09-01 Added hardware v1.0 files
    [high-accuracy-logging-volt-ampmeter-B_Cu.gbr, high-accuracy-logging-volt-ampmeter-B_Mask.gbr, high-accuracy-logging-volt-ampmeter-B_Paste.gbr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]
2021-09-02 Added firmware v1.0 files
    [STM32F103C8T6_powermeter-interface Debug.cfg]
2021-09-03 Added wiring diagram
    [wiring-diagram_diy-logging-volt-ampmeter.kicad_pcb, wiring-diagram_diy-logging-volt-ampmeter.sch]
2021-12-10 Started printing date before time and removed day-printing on last line
2021-12-12 Updated wiring diagram with new power-conversion board with power path
2021-12-12 Updated wiring-diagram png

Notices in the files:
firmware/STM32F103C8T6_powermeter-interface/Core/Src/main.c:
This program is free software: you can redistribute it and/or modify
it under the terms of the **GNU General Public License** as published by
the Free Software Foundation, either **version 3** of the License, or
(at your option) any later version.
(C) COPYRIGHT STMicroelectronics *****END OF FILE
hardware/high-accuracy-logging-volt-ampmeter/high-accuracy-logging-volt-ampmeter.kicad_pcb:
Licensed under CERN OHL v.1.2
